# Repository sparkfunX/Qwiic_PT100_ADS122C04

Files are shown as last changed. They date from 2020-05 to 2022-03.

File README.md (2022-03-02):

# Qwiic PT100 ADS122C04

The Qwiic PT100 is based on the TI ADS122C04 and allows you to measure temperature accurately from
100 Ohm Platinum Resistance Thermometers using 2, 3 or 4-wire connections



[Qwiic PT100 - ADS122C04 (SPX-16770)](https://www.sparkfun.com/products/16770)

The ADS122C04 is a precision 24-bit delta-sigma analog to digital converter. It can measure voltage very
accurately through two differential or four single-ended inputs. It has a flexible input multiplexer,
a low-noise programmable gain amplifier, two programmable current sources, a voltage reference
and an in-built precision temperature sensor. In summary, it contains everything you need to measure
temperature accurately from remote sensors.

The Qwiic PT100 is dedicated to reading the temperature of 100 Ohm Platinum Resistance Thermometers
using 2, 3 or 4-wire connections. Using a 3 or 4-wire connection allows the ADS122C04 to automatically
compensate for the cable resistance. The differential input provides noise rejection for industrial
applications.

The ADS122C04 features a 2-wire I2C-compatible interface. The chip address can be changed by
reconfiguring the two jumpers A0 and A1. Please see the schematic for further details.

## Repository Contents
- **/Hardware** - Eagle schematic and PCB design files
- **/Documents** - contains the TI datasheet and application reports
- **LICENSE.md** contains the licence information

## Library

- **[Arduino Library](https://github.com/sparkfun/SparkFun_ADS122C04_ADC_Arduino_Library)** - Library to support the ADS122C04

## Probe Disconnection

If you need to test if the PT100 probe has been connected correctly to the ADS122C04, you may find [this discussion](https://forum.sparkfun.com/viewtopic.php?p=231735#p231735) useful.

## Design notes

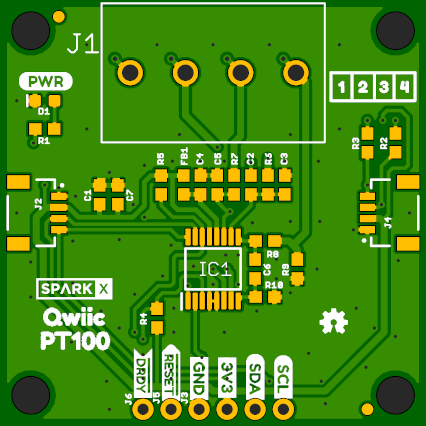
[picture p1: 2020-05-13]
img/Top.png

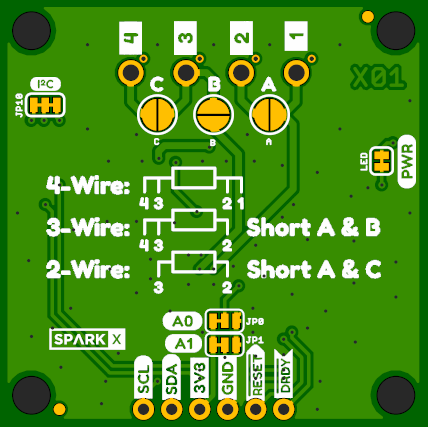
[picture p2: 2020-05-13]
img/Bottom.png

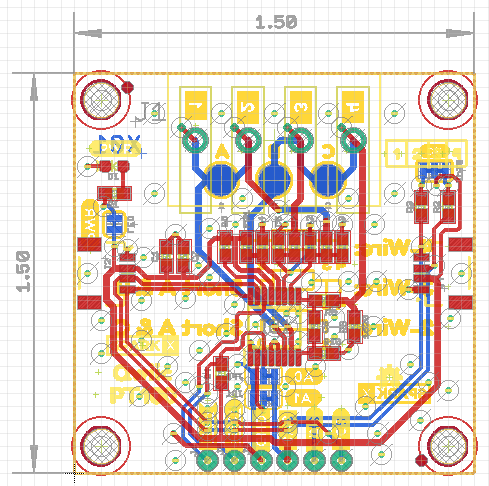
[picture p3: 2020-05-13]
img/Dimension.png

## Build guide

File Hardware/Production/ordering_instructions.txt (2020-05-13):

panel size, 168x161mm
PCB thickness, 1.6mm
number of layers, 2
soldermask color, Black
silkscreen color, White
oz copper, 1oz
finish, HASL lead free
stencils, top+bottom
pcs per panel, 16
min trace width, 0.3048mm / 0.0120in
min drill size, 0.3048mm / 0.0120in

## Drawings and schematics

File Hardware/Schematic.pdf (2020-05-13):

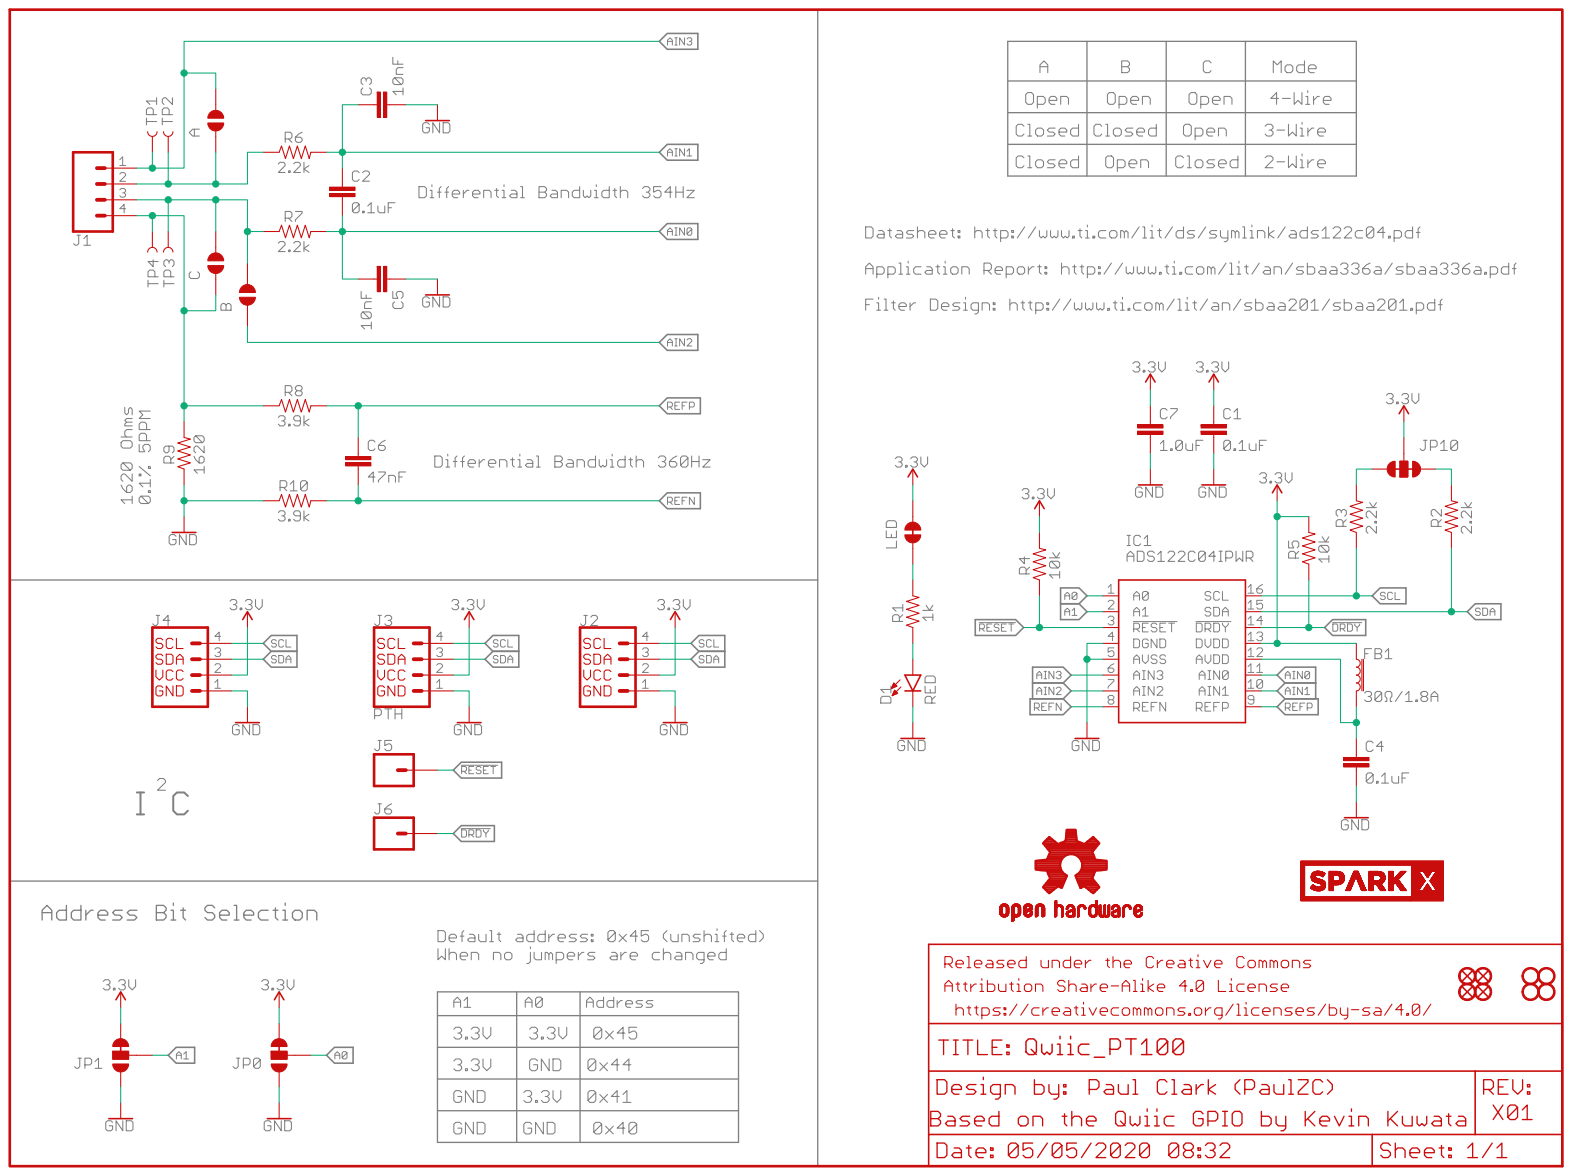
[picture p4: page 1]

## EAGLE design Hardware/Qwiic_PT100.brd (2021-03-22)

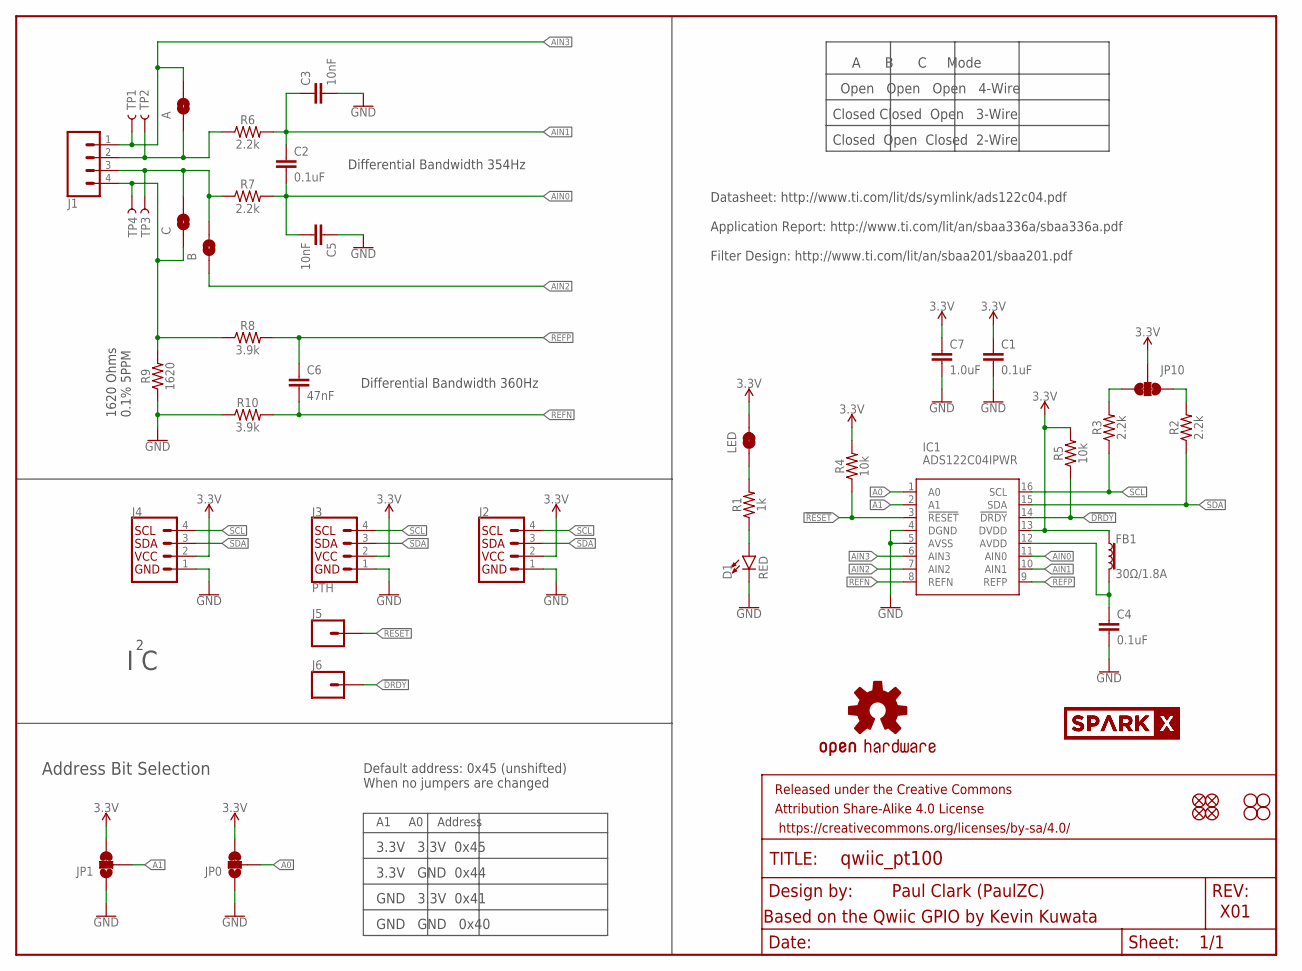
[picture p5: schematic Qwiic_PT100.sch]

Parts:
A: JUMPER-SMT_2_NO_SILK_ROUND; SMT-JUMPER_2_NO_SILK_ROUND
B: JUMPER-SMT_2_NO_SILK_ROUND; SMT-JUMPER_2_NO_SILK_ROUND
C: JUMPER-SMT_2_NO_SILK_ROUND; SMT-JUMPER_2_NO_SILK_ROUND
C1, C2, C4: 0.1uF; 0603
C3, C5: 10nF; 0603
C6: 47nF; 0603
C7: 1.0uF; 0603
D1: RED; LED-0603
FB1: 30Ω/1.8A; 0603
FD1, FD2: FIDUCIAL1X2; FIDUCIAL-1X2
FRAME1: FRAME-LETTER; CREATIVE_COMMONS
H1, H2: STAND-OFF
IC1: ADS122C04IPWR; SOP65P640X120-16N
J1: CONN_04LATCH; LATCHTERMINAL-5MM-4
J2, J4: QWIIC_RIGHT_ANGLE; JST04_1MM_RA
J3: PTH; 1X04_NO_SILK
J5, J6: CONN_01PTH_NO_SILK_YES_STOP; 1X01_NO_SILK
JP0, JP1: JUMPER-SMT_3_1-NC_TRACE_SILK; SMT-JUMPER_3_1-NC_TRACE_SILK
JP2, JP6: FIDUCIAL1X2; FIDUCIAL-1X2
JP3, JP4: STAND-OFF
JP10: JUMPER-SMT_3_2-NC_TRACE_SILK; SMT-JUMPER_3_2-NC_TRACE_SILK
LED: JUMPER-SMT_2_NC_TRACE_SILK; SMT-JUMPER_2_NC_TRACE_SILK
LOGO1: OSHW-LOGOMINI; OSHW-LOGO-MINI
R1: 1k; 0603
R2, R3, R6, R7: 2.2k; 0603
R4, R5: 10k; 0603
R8, R10: 3.9k; 0603
R9: 1620; 0603
TP1, TP2, TP3, TP4: TEST-POINTTP_15TH_THRU; TP_15TH
U$1, U$2: SPARKX-LOGO3; SPARKX-SMALL

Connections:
3.3V: C1.1, C7.1, FB1.1, IC1.13 (DVDD), J2.2, J3.2, J4.2, JP0.3, JP1.3, JP10.2, LED.2, R4.2, R5.2
!DRDY: IC1.14 (!DRDY), J6.1, R5.1
!RESET: IC1.3 (!RESET), J5.1, R4.1
A0: IC1.1 (A0), JP0.2
A1: IC1.2 (A1), JP1.2
AIN0: C2.2, C5.2, IC1.11 (AIN0), R7.2
AIN1: C2.1, C3.1, IC1.10 (AIN1), R6.2
AIN2: B.1, IC1.7 (AIN2)
AIN3: A.2, IC1.6 (AIN3), J1.1, TP1.P$1
GND: C1.2, C3.2, C4.2, C5.1, C7.2, D1.C, IC1.4 (DGND), IC1.5 (AVSS), J2.1, J3.1, J4.1, JP0.1, JP1.1, R9.1, R10.1
unnamed: A.1, J1.2, R6.1, TP2.P$1
unnamed: D1.A, R1.1
unnamed: LED.1, R1.2
unnamed: C4.1, FB1.2, IC1.12 (AVDD)
unnamed: B.2, C.2, J1.3, R7.1, TP3.P$1
unnamed: C.1, J1.4, R8.1, R9.2, TP4.P$1
REFN: C6.2, IC1.8 (REFN), R10.2
REFP: C6.1, IC1.9 (REFP), R8.2
SCL: IC1.16 (SCL), J2.4, J3.4, J4.4, R3.1
SCL_PU1: JP10.1, R2.2
SDA: IC1.15 (SDA), J2.3, J3.3, J4.3, R2.1
SDA_PU1: JP10.3, R3.2

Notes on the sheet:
Paul Clark (PaulZC)
X01
I C
Address Bit Selection
A1 A0 Address
3.3V 3.3V 0x45
3.3V GND 0x44
GND 3.3V 0x41
GND GND 0x40
Default address: 0x45 (unshifted) When no jumpers are changed
Based on the Qwiic GPIO by Kevin Kuwata
A B C Mode
Open Open Open 4-Wire
Closed Closed Open 3-Wire
Closed Open Closed 2-Wire
Datasheet: http://www.ti.com/lit/ds/symlink/ads122c04.pdf Application Report: http://www.ti.com/lit/an/sbaa336a/sbaa336a.pdf Filter Design: http://www.ti.com/lit/an/sbaa201/sbaa201.pdf
1620 Ohms 0.1% 5PPM
Differential Bandwidth 354Hz
Differential Bandwidth 360Hz

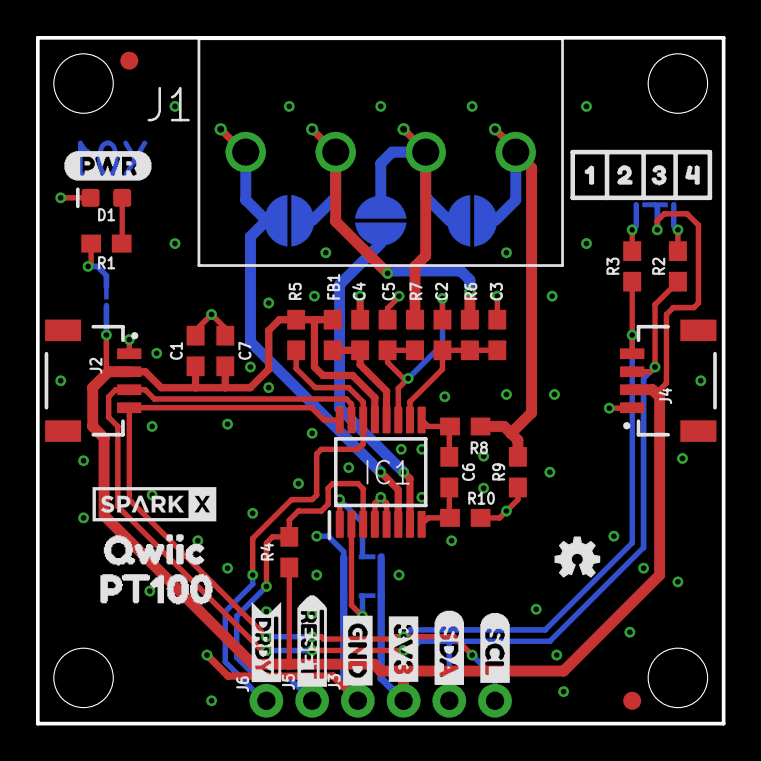
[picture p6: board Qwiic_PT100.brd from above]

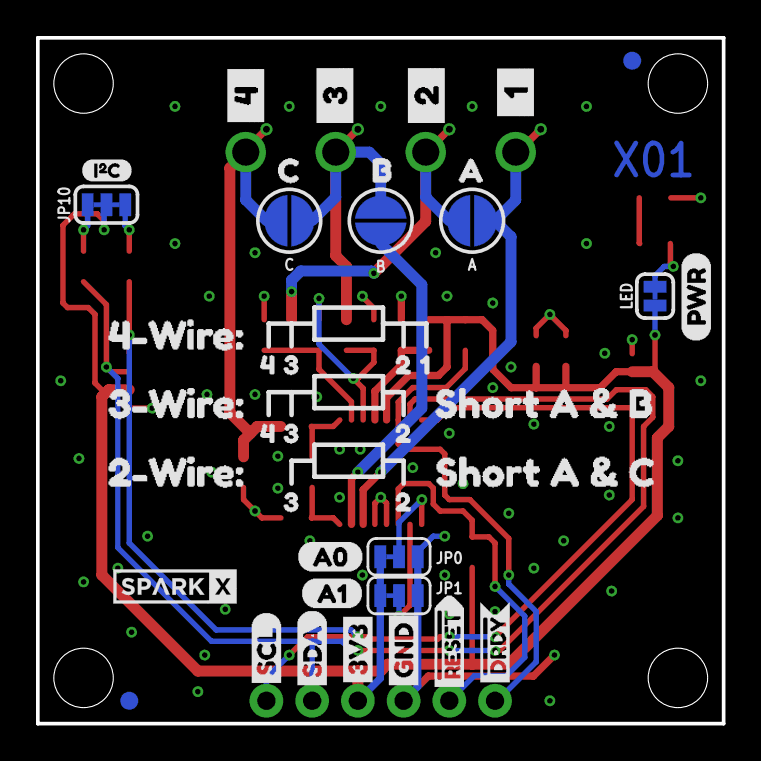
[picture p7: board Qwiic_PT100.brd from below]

Board: 2 copper layers, 38.1 x 38.1 mm, 93 parts (41 on the bottom side), 22 nets.

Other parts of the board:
U$3, U$26: 3V33
U$4: _1_0
U$5: A11
U$6: _2_0
U$7, U$25: GND4
U$8: PT1000
U$9: SCL6
U$10: SDA5
U$11: A00
U$12: _3_0
U$13: _4_0
U$14, U$15: #DRDY0
U$16, U$17: #RESET0
U$18: A0
U$19: B0
U$20: I_SUPER2_C-()-03
U$21, U$30, U$44: 40
U$22: C0
U$23: SCL0
U$24: SDA1
U$27, U$34, U$38, U$47: 31
U$28, U$33, U$37, U$46: 20
U$29, U$35: 15
U$31: 2#WIRE#0
U$32: QWIIC1
U$36: 3#WIRE#0
U$39, U$40: PWR0
U$41: 4#WIRE#0
U$42: SHORT_A_#_B0
U$43: SHORT_A_#_C0

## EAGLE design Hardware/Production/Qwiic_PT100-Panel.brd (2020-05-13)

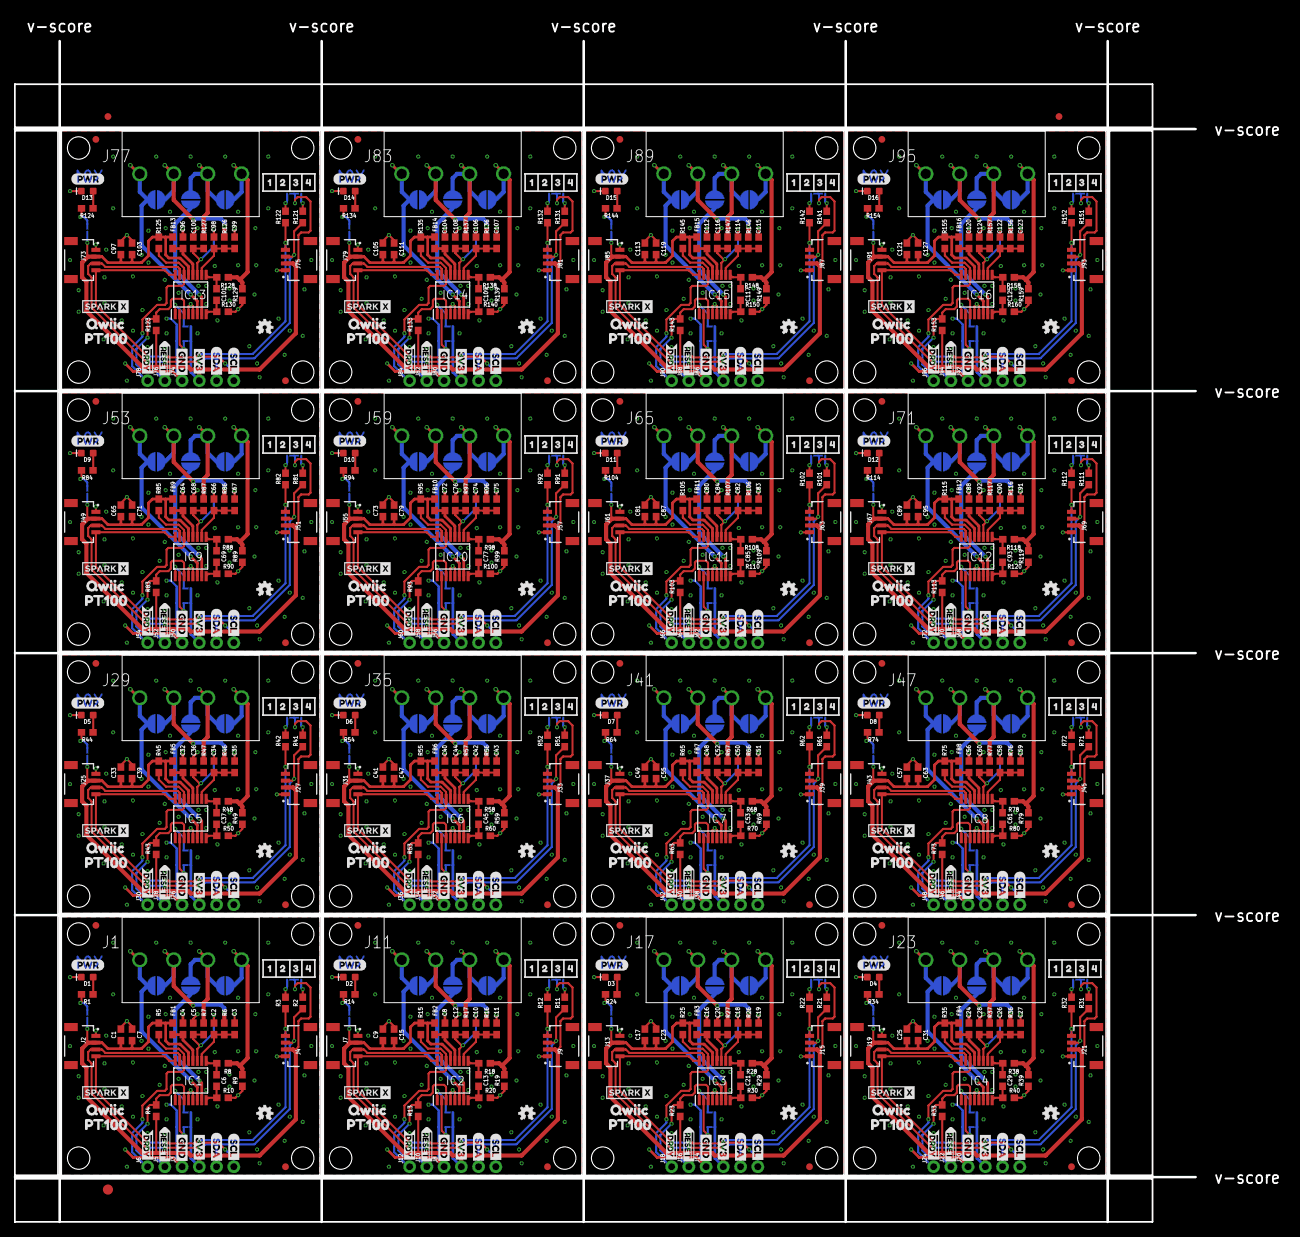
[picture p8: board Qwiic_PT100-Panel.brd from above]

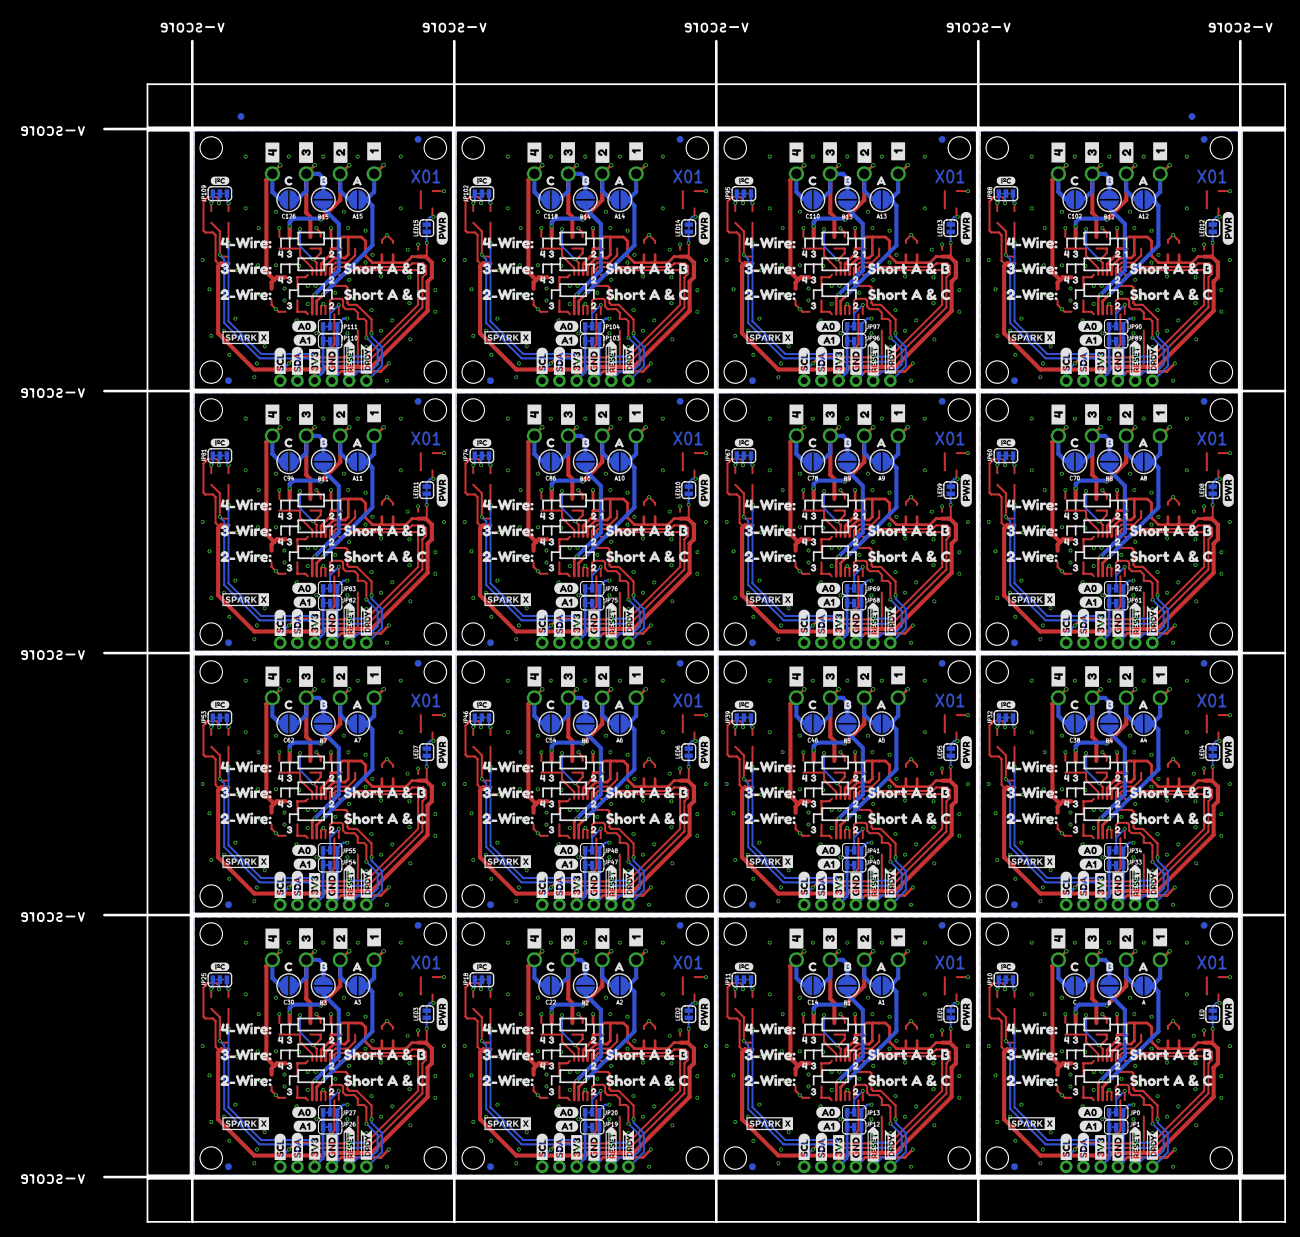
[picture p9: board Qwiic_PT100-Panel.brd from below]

Board: 2 copper layers, 174.0 x 174.0 mm, 1477 parts (658 on the bottom side), 352 nets.

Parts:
A, A1, A2, A3, A4, A5, A6, A7, A8, A9, A10, A11, A12, A13, A14, A15: JUMPER-SMT_2_NO_SILK_ROUND; SMT-JUMPER_2_NO_SILK_ROUND
B, B1, B2, B3, B4, B5, B6, B7, B8, B9, B10, B11, B12, B13, B14, B15: JUMPER-SMT_2_NO_SILK_ROUND; SMT-JUMPER_2_NO_SILK_ROUND
C, C14, C22, C30, C38, C46, C54, C62, C70, C78, C86, C94, C102, C110, C118, C126: JUMPER-SMT_2_NO_SILK_ROUND; SMT-JUMPER_2_NO_SILK_ROUND
C1, C2, C4, C8, C9, C10, C16, C17, C18, C24, C25, C26, C32, C33, C34, C40, C41, C42, C48, C49, C50, C56, C57, C58, C64, C65, C66, C72, C73, C74, C80, C81, C82, C88, C89, C90, C96, C97, C98, C104, C105, C106, C112, C113, C114, C120, C121, C122: 0.1uF; 0603
C3, C5, C11, C12, C19, C20, C27, C28, C35, C36, C43, C44, C51, C52, C59, C60, C67, C68, C75, C76, C83, C84, C91, C92, C99, C100, C107, C108, C115, C116, C123, C124: 10nF; 0603
C6, C13, C21, C29, C37, C45, C53, C61, C69, C77, C85, C93, C101, C109, C117, C125: 47nF; 0603
C7, C15, C23, C31, C39, C47, C55, C63, C71, C79, C87, C95, C103, C111, C119, C127: 1.0uF; 0603
D1, D2, D3, D4, D5, D6, D7, D8, D9, D10, D11, D12, D13, D14, D15, D16: RED; LED-0603
E$1, E$2, E$3, E$4: FIDUCIAL-1X2
E$5: FIDUCIAL-1.5X3
FB1, FB2, FB3, FB4, FB5, FB6, FB7, FB8, FB9, FB10, FB11, FB12, FB13, FB14, FB15, FB16: 30Ω/1.8A; 0603
FD1, FD2, FD3, FD4, FD5, FD6, FD7, FD8, FD9, FD10, FD11, FD12, FD13, FD14, FD15, FD16, FD17, FD18, FD19, FD20, FD21, FD22, FD23, FD24, FD25, FD26, FD27, FD28, FD29, FD30, FD31, FD32: FIDUCIAL1X2; FIDUCIAL-1X2
H1, H2, H3, H4, H5, H6, H7, H8, H9, H10, H11, H12, H13, H14, H15, H16, H17, H18, H19, H20, H21, H22, H23, H24, H25, H26, H27, H28, H29, H30, H31, H32: STAND-OFF
IC1, IC2, IC3, IC4, IC5, IC6, IC7, IC8, IC9, IC10, IC11, IC12, IC13, IC14, IC15, IC16: ADS122C04IPWR; SOP65P640X120-16N
J1, J11, J17, J23, J29, J35, J41, J47, J53, J59, J65, J71, J77, J83, J89, J95: LATCHTERMINAL-5MM-4
J2, J4, J7, J9, J13, J15, J19, J21, J25, J27, J31, J33, J37, J39, J43, J45, J49, J51, J55, J57, J61, J63, J67, J69, J73, J75, J79, J81, J85, J87, J91, J93: QWIIC_RIGHT_ANGLE; JST04_1MM_RA
J3, J8, J14, J20, J26, J32, J38, J44, J50, J56, J62, J68, J74, J80, J86, J92: PTH; 1X04_NO_SILK
J5, J6, J10, J12, J16, J18, J22, J24, J28, J30, J34, J36, J40, J42, J46, J48, J52, J54, J58, J60, J64, J66, J70, J72, J76, J78, J82, J84, J88, J90, J94, J96: 1X01_NO_SILK
JP0, JP1, JP12, JP13, JP19, JP20, JP26, JP27, JP33, JP34, JP40, JP41, JP47, JP48, JP54, JP55, JP61, JP62, JP68, JP69, JP75, JP76, JP82, JP83, JP89, JP90, JP96, JP97, JP103, JP104, JP110, JP111: JUMPER-SMT_3_1-NC_TRACE_SILK; SMT-JUMPER_3_1-NC_TRACE_SILK
JP2, JP6, JP8, JP9, JP16, JP17, JP23, JP24, JP30, JP31, JP37, JP38, JP44, JP45, JP51, JP52, JP58, JP59, JP65, JP66, JP72, JP73, JP79, JP80, JP86, JP87, JP93, JP94, JP100, JP101, JP107, JP108: FIDUCIAL1X2; FIDUCIAL-1X2
JP3, JP4, JP5, JP7, JP14, JP15, JP21, JP22, JP28, JP29, JP35, JP36, JP42, JP43, JP49, JP50, JP56, JP57, JP63, JP64, JP70, JP71, JP77, JP78, JP84, JP85, JP91, JP92, JP98, JP99, JP105, JP106: STAND-OFF
JP10, JP11, JP18, JP25, JP32, JP39, JP46, JP53, JP60, JP67, JP74, JP81, JP88, JP95, JP102, JP109: JUMPER-SMT_3_2-NC_TRACE_SILK; SMT-JUMPER_3_2-NC_TRACE_SILK
LED, LED1, LED2, LED3, LED4, LED5, LED6, LED7, LED8, LED9, LED10, LED11, LED12, LED13, LED14, LED15: JUMPER-SMT_2_NC_TRACE_SILK; SMT-JUMPER_2_NC_TRACE_SILK
LOGO1, LOGO2, LOGO3, LOGO4, LOGO5, LOGO6, LOGO7, LOGO8, LOGO9, LOGO10, LOGO11, LOGO12, LOGO13, LOGO14, LOGO15, LOGO16: OSHW-LOGOMINI; OSHW-LOGO-MINI
R1, R14, R24, R34, R44, R54, R64, R74, R84, R94, R104, R114, R124, R134, R144, R154: 1k; 0603
R2, R3, R6, R7, R11, R12, R16, R17, R21, R22, R26, R27, R31, R32, R36, R37, R41, R42, R46, R47, R51, R52, R56, R57, R61, R62, R66, R67, R71, R72, R76, R77, R81, R82, R86, R87, R91, R92, R96, R97, R101, R102, R106, R107, R111, R112, R116, R117, R121, R122, R126, R127, R131, R132, R136, R137, R141, R142, R146, R147, R151, R152, R156, R157: 2.2k; 0603
R4, R5, R13, R15, R23, R25, R33, R35, R43, R45, R53, R55, R63, R65, R73, R75, R83, R85, R93, R95, R103, R105, R113, R115, R123, R125, R133, R135, R143, R145, R153, R155: 10k; 0603
R8, R10, R18, R20, R28, R30, R38, R40, R48, R50, R58, R60, R68, R70, R78, R80, R88, R90, R98, R100, R108, R110, R118, R120, R128, R130, R138, R140, R148, R150, R158, R160: 3.9k; 0603
R9, R19, R29, R39, R49, R59, R69, R79, R89, R99, R109, R119, R129, R139, R149, R159: 1620; 0603
TP1, TP2, TP3, TP4, TP5, TP6, TP7, TP8, TP9, TP10, TP11, TP12, TP13, TP14, TP15, TP16, TP17, TP18, TP19, TP20, TP21, TP22, TP23, TP24, TP25, TP26, TP27, TP28, TP29, TP30, TP31, TP32, TP33, TP34, TP35, TP36, TP37, TP38, TP39, TP40, TP41, TP42, TP43, TP44, TP45, TP46, TP47, TP48, TP49, TP50, TP51, TP52, TP53, TP54, TP55, TP56, TP57, TP58, TP59, TP60, TP61, TP62, TP63, TP64: TEST-POINTTP_15TH_THRU; TP_15TH
U$1, U$2, U$45, U$48, U$93, U$94, U$139, U$140, U$185, U$186, U$231, U$232, U$277, U$278, U$323, U$324, U$369, U$370, U$415, U$416, U$461, U$462, U$507, U$508, U$553, U$554, U$599, U$600, U$645, U$646, U$691, U$692: SPARKX-LOGO3; SPARKX-SMALL
U$3, U$26, U$49, U$59, U$95, U$105, U$141, U$151, U$187, U$197, U$233, U$243, U$279, U$289, U$325, U$335, U$371, U$381, U$417, U$427, U$463, U$473, U$509, U$519, U$555, U$565, U$601, U$611, U$647, U$657, U$693, U$703: 3V33
U$4, U$66, U$112, U$158, U$204, U$250, U$296, U$342, U$388, U$434, U$480, U$526, U$572, U$618, U$664, U$710: _1_0
U$5, U$50, U$96, U$142, U$188, U$234, U$280, U$326, U$372, U$418, U$464, U$510, U$556, U$602, U$648, U$694: A11
U$6, U$67, U$113, U$159, U$205, U$251, U$297, U$343, U$389, U$435, U$481, U$527, U$573, U$619, U$665, U$711: _2_0
U$7, U$25, U$51, U$58, U$97, U$104, U$143, U$150, U$189, U$196, U$235, U$242, U$281, U$288, U$327, U$334, U$373, U$380, U$419, U$426, U$465, U$472, U$511, U$518, U$557, U$564, U$603, U$610, U$649, U$656, U$695, U$702: GND4
U$8, U$78, U$124, U$170, U$216, U$262, U$308, U$354, U$400, U$446, U$492, U$538, U$584, U$630, U$676, U$722: PT1000
U$9, U$52, U$98, U$144, U$190, U$236, U$282, U$328, U$374, U$420, U$466, U$512, U$558, U$604, U$650, U$696: SCL6
U$10, U$53, U$99, U$145, U$191, U$237, U$283, U$329, U$375, U$421, U$467, U$513, U$559, U$605, U$651, U$697: SDA5
U$11, U$54, U$100, U$146, U$192, U$238, U$284, U$330, U$376, U$422, U$468, U$514, U$560, U$606, U$652, U$698: A00
U$12, U$68, U$114, U$160, U$206, U$252, U$298, U$344, U$390, U$436, U$482, U$528, U$574, U$620, U$666, U$712: _3_0
U$13, U$69, U$115, U$161, U$207, U$253, U$299, U$345, U$391, U$437, U$483, U$529, U$575, U$621, U$667, U$713: _4_0
U$14, U$15, U$70, U$71, U$116, U$117, U$162, U$163, U$208, U$209, U$254, U$255, U$300, U$301, U$346, U$347, U$392, U$393, U$438, U$439, U$484, U$485, U$530, U$531, U$576, U$577, U$622, U$623, U$668, U$669, U$714, U$715: #DRDY0
U$16, U$17, U$72, U$73, U$118, U$119, U$164, U$165, U$210, U$211, U$256, U$257, U$302, U$303, U$348, U$349, U$394, U$395, U$440, U$441, U$486, U$487, U$532, U$533, U$578, U$579, U$624, U$625, U$670, U$671, U$716, U$717: #RESET0
U$18, U$74, U$120, U$166, U$212, U$258, U$304, U$350, U$396, U$442, U$488, U$534, U$580, U$626, U$672, U$718: A0
U$19, U$75, U$121, U$167, U$213, U$259, U$305, U$351, U$397, U$443, U$489, U$535, U$581, U$627, U$673, U$719: B0
U$20, U$55, U$101, U$147, U$193, U$239, U$285, U$331, U$377, U$423, U$469, U$515, U$561, U$607, U$653, U$699: I_SUPER2_C-()-03
U$21, U$30, U$44, U$77, U$86, U$89, U$123, U$132, U$135, U$169, U$178, U$181, U$215, U$224, U$227, U$261, U$270, U$273, U$307, U$316, U$319, U$353, U$362, U$365, U$399, U$408, U$411, U$445, U$454, U$457, U$491, U$500, U$503, U$537, U$546, U$549, U$583, U$592, U$595, U$629, U$638, U$641, U$675, U$684, U$687, U$721, U$730, U$733: 40
U$22, U$76, U$122, U$168, U$214, U$260, U$306, U$352, U$398, U$444, U$490, U$536, U$582, U$628, U$674, U$720: C0
U$23, U$56, U$102, U$148, U$194, U$240, U$286, U$332, U$378, U$424, U$470, U$516, U$562, U$608, U$654, U$700: SCL0
U$24, U$57, U$103, U$149, U$195, U$241, U$287, U$333, U$379, U$425, U$471, U$517, U$563, U$609, U$655, U$701: SDA1
U$27, U$34, U$38, U$47, U$63, U$85, U$88, U$90, U$109, U$131, U$134, U$136, U$155, U$177, U$180, U$182, U$201, U$223, U$226, U$228, U$247, U$269, U$272, U$274, U$293, U$315, U$318, U$320, U$339, U$361, U$364, U$366, U$385, U$407, U$410, U$412, U$431, U$453, U$456, U$458, U$477, U$499, U$502, U$504, U$523, U$545, U$548, U$550, U$569, U$591, U$594, U$596, U$615, U$637, U$640, U$642, U$661, U$683, U$686, U$688, U$707, U$729, U$732, U$734: 31
U$28, U$33, U$37, U$46, U$62, U$84, U$87, U$91, U$108, U$130, U$133, U$137, U$154, U$176, U$179, U$183, U$200, U$222, U$225, U$229, U$246, U$268, U$271, U$275, U$292, U$314, U$317, U$321, U$338, U$360, U$363, U$367, U$384, U$406, U$409, U$413, U$430, U$452, U$455, U$459, U$476, U$498, U$501, U$505, U$522, U$544, U$547, U$551, U$568, U$590, U$593, U$597, U$614, U$636, U$639, U$643, U$660, U$682, U$685, U$689, U$706, U$728, U$731, U$735: 20
U$29, U$35, U$61, U$92, U$107, U$138, U$153, U$184, U$199, U$230, U$245, U$276, U$291, U$322, U$337, U$368, U$383, U$414, U$429, U$460, U$475, U$506, U$521, U$552, U$567, U$598, U$613, U$644, U$659, U$690, U$705, U$736: 15
U$31, U$79, U$125, U$171, U$217, U$263, U$309, U$355, U$401, U$447, U$493, U$539, U$585, U$631, U$677, U$723: 2#WIRE#0
U$32, U$60, U$106, U$152, U$198, U$244, U$290, U$336, U$382, U$428, U$474, U$520, U$566, U$612, U$658, U$704: QWIIC1
U$36, U$80, U$126, U$172, U$218, U$264, U$310, U$356, U$402, U$448, U$494, U$540, U$586, U$632, U$678, U$724: 3#WIRE#0
U$39, U$40, U$64, U$65, U$110, U$111, U$156, U$157, U$202, U$203, U$248, U$249, U$294, U$295, U$340, U$341, U$386, U$387, U$432, U$433, U$478, U$479, U$524, U$525, U$570, U$571, U$616, U$617, U$662, U$663, U$708, U$709: PWR0
U$41, U$81, U$127, U$173, U$219, U$265, U$311, U$357, U$403, U$449, U$495, U$541, U$587, U$633, U$679, U$725: 4#WIRE#0
U$42, U$82, U$128, U$174, U$220, U$266, U$312, U$358, U$404, U$450, U$496, U$542, U$588, U$634, U$680, U$726: SHORT_A_#_B0
U$43, U$83, U$129, U$175, U$221, U$267, U$313, U$359, U$405, U$451, U$497, U$543, U$589, U$635, U$681, U$727: SHORT_A_#_C0

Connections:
3.3V: C1.1, C7.1, FB1.1, IC1.13, J2.2, J3.2, J4.2, JP0.3, JP1.3, JP10.2, LED.2, R4.2, R5.2
3.3V1: C9.1, C15.1, FB2.1, IC2.13, J7.2, J8.2, J9.2, JP11.2, JP12.3, JP13.3, LED1.2, R13.2, R15.2
3.3V2: C17.1, C23.1, FB3.1, IC3.13, J13.2, J14.2, J15.2, JP18.2, JP19.3, JP20.3, LED2.2, R23.2, R25.2
3.3V3: C25.1, C31.1, FB4.1, IC4.13, J19.2, J20.2, J21.2, JP25.2, JP26.3, JP27.3, LED3.2, R33.2, R35.2
3.3V4: C33.1, C39.1, FB5.1, IC5.13, J25.2, J26.2, J27.2, JP32.2, JP33.3, JP34.3, LED4.2, R43.2, R45.2
3.3V5: C41.1, C47.1, FB6.1, IC6.13, J31.2, J32.2, J33.2, JP39.2, JP40.3, JP41.3, LED5.2, R53.2, R55.2
3.3V6: C49.1, C55.1, FB7.1, IC7.13, J37.2, J38.2, J39.2, JP46.2, JP47.3, JP48.3, LED6.2, R63.2, R65.2
3.3V7: C57.1, C63.1, FB8.1, IC8.13, J43.2, J44.2, J45.2, JP53.2, JP54.3, JP55.3, LED7.2, R73.2, R75.2
3.3V8: C65.1, C71.1, FB9.1, IC9.13, J49.2, J50.2, J51.2, JP60.2, JP61.3, JP62.3, LED8.2, R83.2, R85.2
3.3V9: C73.1, C79.1, FB10.1, IC10.13, J55.2, J56.2, J57.2, JP67.2, JP68.3, JP69.3, LED9.2, R93.2, R95.2
3.3V10: C81.1, C87.1, FB11.1, IC11.13, J61.2, J62.2, J63.2, JP74.2, JP75.3, JP76.3, LED10.2, R103.2, R105.2
3.3V11: C89.1, C95.1, FB12.1, IC12.13, J67.2, J68.2, J69.2, JP81.2, JP82.3, JP83.3, LED11.2, R113.2, R115.2
3.3V12: C97.1, C103.1, FB13.1, IC13.13, J73.2, J74.2, J75.2, JP88.2, JP89.3, JP90.3, LED12.2, R123.2, R125.2
3.3V13: C105.1, C111.1, FB14.1, IC14.13, J79.2, J80.2, J81.2, JP95.2, JP96.3, JP97.3, LED13.2, R133.2, R135.2
3.3V14: C113.1, C119.1, FB15.1, IC15.13, J85.2, J86.2, J87.2, JP102.2, JP103.3, JP104.3, LED14.2, R143.2, R145.2
3.3V15: C121.1, C127.1, FB16.1, IC16.13, J91.2, J92.2, J93.2, JP109.2, JP110.3, JP111.3, LED15.2, R153.2, R155.2
!DRDY: IC1.14, J6.1, R5.1
!DRDY1: IC2.14, J12.1, R15.1
!DRDY2: IC3.14, J18.1, R25.1
!DRDY3: IC4.14, J24.1, R35.1
!DRDY4: IC5.14, J30.1, R45.1
!DRDY5: IC6.14, J36.1, R55.1
!DRDY6: IC7.14, J42.1, R65.1
!DRDY7: IC8.14, J48.1, R75.1
!DRDY8: IC9.14, J54.1, R85.1
!DRDY9: IC10.14, J60.1, R95.1
!DRDY10: IC11.14, J66.1, R105.1
!DRDY11: IC12.14, J72.1, R115.1
!DRDY12: IC13.14, J78.1, R125.1
!DRDY13: IC14.14, J84.1, R135.1
!DRDY14: IC15.14, J90.1, R145.1
!DRDY15: IC16.14, J96.1, R155.1
!RESET: IC1.3, J5.1, R4.1
!RESET1: IC2.3, J10.1, R13.1
!RESET2: IC3.3, J16.1, R23.1
!RESET3: IC4.3, J22.1, R33.1
!RESET4: IC5.3, J28.1, R43.1
!RESET5: IC6.3, J34.1, R53.1
!RESET6: IC7.3, J40.1, R63.1
!RESET7: IC8.3, J46.1, R73.1
!RESET8: IC9.3, J52.1, R83.1
!RESET9: IC10.3, J58.1, R93.1
!RESET10: IC11.3, J64.1, R103.1
!RESET11: IC12.3, J70.1, R113.1
!RESET12: IC13.3, J76.1, R123.1
!RESET13: IC14.3, J82.1, R133.1
!RESET14: IC15.3, J88.1, R143.1
!RESET15: IC16.3, J94.1, R153.1
A0: IC1.1, JP0.2
A1: IC1.2, JP1.2
A2: IC2.1, JP13.2
A3: IC2.2, JP12.2
A4: IC3.1, JP20.2
A5: IC3.2, JP19.2
A6: IC4.1, JP27.2
A7: IC4.2, JP26.2
A8: IC5.1, JP34.2
A9: IC5.2, JP33.2
A10: IC6.1, JP41.2
A11: IC6.2, JP40.2
A12: IC7.1, JP48.2
A13: IC7.2, JP47.2
A14: IC8.1, JP55.2
A15: IC8.2, JP54.2
A16: IC9.1, JP62.2
A17: IC9.2, JP61.2
A18: IC10.1, JP69.2
A19: IC10.2, JP68.2
A20: IC11.1, JP76.2
A21: IC11.2, JP75.2
A22: IC12.1, JP83.2
A23: IC12.2, JP82.2
A24: IC13.1, JP90.2
A25: IC13.2, JP89.2
A26: IC14.1, JP97.2
A27: IC14.2, JP96.2
A28: IC15.1, JP104.2
A29: IC15.2, JP103.2
A30: IC16.1, JP111.2
A31: IC16.2, JP110.2
AIN0: C2.2, C5.2, IC1.11, R7.2
AIN1: C2.1, C3.1, IC1.10, R6.2
AIN2: B.1, IC1.7
AIN3: A.2, IC1.6, J1.1, TP1.P$1
AIN4: C10.1, C11.1, IC2.10, R16.2
AIN5: A1.2, IC2.6, J11.1, TP5.P$1
AIN6: B1.1, IC2.7
AIN7: C10.2, C12.2, IC2.11, R17.2
AIN8: C18.1, C19.1, IC3.10, R26.2
AIN9: A2.2, IC3.6, J17.1, TP9.P$1
AIN10: B2.1, IC3.7
AIN11: C18.2, C20.2, IC3.11, R27.2
AIN12: C26.1, C27.1, IC4.10, R36.2
AIN13: A3.2, IC4.6, J23.1, TP13.P$1
AIN14: B3.1, IC4.7
AIN15: C26.2, C28.2, IC4.11, R37.2
AIN16: C34.1, C35.1, IC5.10, R46.2
AIN17: A4.2, IC5.6, J29.1, TP17.P$1
AIN18: B4.1, IC5.7
AIN19: C34.2, C36.2, IC5.11, R47.2
AIN20: C42.1, C43.1, IC6.10, R56.2
AIN21: A5.2, IC6.6, J35.1, TP21.P$1
AIN22: B5.1, IC6.7
AIN23: C42.2, C44.2, IC6.11, R57.2
AIN24: C50.1, C51.1, IC7.10, R66.2
AIN25: A6.2, IC7.6, J41.1, TP25.P$1
AIN26: B6.1, IC7.7
AIN27: C50.2, C52.2, IC7.11, R67.2
AIN28: C58.1, C59.1, IC8.10, R76.2
AIN29: A7.2, IC8.6, J47.1, TP29.P$1
AIN30: B7.1, IC8.7
AIN31: C58.2, C60.2, IC8.11, R77.2
AIN32: C66.1, C67.1, IC9.10, R86.2
AIN33: A8.2, IC9.6, J53.1, TP33.P$1
AIN34: B8.1, IC9.7
AIN35: C66.2, C68.2, IC9.11, R87.2
AIN36: C74.1, C75.1, IC10.10, R96.2
AIN37: A9.2, IC10.6, J59.1, TP37.P$1
AIN38: B9.1, IC10.7
AIN39: C74.2, C76.2, IC10.11, R97.2
AIN40: C82.1, C83.1, IC11.10, R106.2
AIN41: A10.2, IC11.6, J65.1, TP41.P$1
AIN42: B10.1, IC11.7
AIN43: C82.2, C84.2, IC11.11, R107.2
AIN44: C90.1, C91.1, IC12.10, R116.2
AIN45: A11.2, IC12.6, J71.1, TP45.P$1
AIN46: B11.1, IC12.7
AIN47: C90.2, C92.2, IC12.11, R117.2
AIN48: C98.1, C99.1, IC13.10, R126.2
AIN49: A12.2, IC13.6, J77.1, TP49.P$1
AIN50: B12.1, IC13.7
AIN51: C98.2, C100.2, IC13.11, R127.2
AIN52: C106.1, C107.1, IC14.10, R136.2
AIN53: A13.2, IC14.6, J83.1, TP53.P$1
AIN54: B13.1, IC14.7
AIN55: C106.2, C108.2, IC14.11, R137.2
AIN56: C114.1, C115.1, IC15.10, R146.2
AIN57: A14.2, IC15.6, J89.1, TP57.P$1
AIN58: B14.1, IC15.7
AIN59: C114.2, C116.2, IC15.11, R147.2
AIN60: C122.1, C123.1, IC16.10, R156.2
AIN61: A15.2, IC16.6, J95.1, TP61.P$1
AIN62: B15.1, IC16.7
AIN63: C122.2, C124.2, IC16.11, R157.2
GND: C1.2, C3.2, C4.2, C5.1, C7.2, D1.C, IC1.4, IC1.5, J2.1, J3.1, J4.1, JP0.1, JP1.1, R9.1, R10.1
GND1: C8.2, C9.2, C11.2, C12.1, C15.2, D2.C, IC2.4, IC2.5, J7.1, J8.1, J9.1, JP12.1, JP13.1, R19.1, R20.1
GND2: C16.2, C17.2, C19.2, C20.1, C23.2, D3.C, IC3.4, IC3.5, J13.1, J14.1, J15.1, JP19.1, JP20.1, R29.1, R30.1
GND3: C24.2, C25.2, C27.2, C28.1, C31.2, D4.C, IC4.4, IC4.5, J19.1, J20.1, J21.1, JP26.1, JP27.1, R39.1, R40.1
GND4: C32.2, C33.2, C35.2, C36.1, C39.2, D5.C, IC5.4, IC5.5, J25.1, J26.1, J27.1, JP33.1, JP34.1, R49.1, R50.1
GND5: C40.2, C41.2, C43.2, C44.1, C47.2, D6.C, IC6.4, IC6.5, J31.1, J32.1, J33.1, JP40.1, JP41.1, R59.1, R60.1
GND6: C48.2, C49.2, C51.2, C52.1, C55.2, D7.C, IC7.4, IC7.5, J37.1, J38.1, J39.1, JP47.1, JP48.1, R69.1, R70.1
GND7: C56.2, C57.2, C59.2, C60.1, C63.2, D8.C, IC8.4, IC8.5, J43.1, J44.1, J45.1, JP54.1, JP55.1, R79.1, R80.1
GND8: C64.2, C65.2, C67.2, C68.1, C71.2, D9.C, IC9.4, IC9.5, J49.1, J50.1, J51.1, JP61.1, JP62.1, R89.1, R90.1
GND9: C72.2, C73.2, C75.2, C76.1, C79.2, D10.C, IC10.4, IC10.5, J55.1, J56.1, J57.1, JP68.1, JP69.1, R99.1, R100.1
GND10: C80.2, C81.2, C83.2, C84.1, C87.2, D11.C, IC11.4, IC11.5, J61.1, J62.1, J63.1, JP75.1, JP76.1, R109.1, R110.1
GND11: C88.2, C89.2, C91.2, C92.1, C95.2, D12.C, IC12.4, IC12.5, J67.1, J68.1, J69.1, JP82.1, JP83.1, R119.1, R120.1
GND12: C96.2, C97.2, C99.2, C100.1, C103.2, D13.C, IC13.4, IC13.5, J73.1, J74.1, J75.1, JP89.1, JP90.1, R129.1, R130.1
GND13: C104.2, C105.2, C107.2, C108.1, C111.2, D14.C, IC14.4, IC14.5, J79.1, J80.1, J81.1, JP96.1, JP97.1, R139.1, R140.1
GND14: C112.2, C113.2, C115.2, C116.1, C119.2, D15.C, IC15.4, IC15.5, J85.1, J86.1, J87.1, JP103.1, JP104.1, R149.1, R150.1
GND15: C120.2, C121.2, C123.2, C124.1, C127.2, D16.C, IC16.4, IC16.5, J91.1, J92.1, J93.1, JP110.1, JP111.1, R159.1, R160.1
unnamed: A.1, J1.2, R6.1, TP2.P$1
unnamed: D1.A, R1.1
unnamed: LED.1, R1.2
unnamed: C4.1, FB1.2, IC1.12
unnamed: B.2, C.2, J1.3, R7.1, TP3.P$1
unnamed: C.1, J1.4, R8.1, R9.2, TP4.P$1
unnamed: D2.A, R14.1
unnamed: LED1.1, R14.2
unnamed: C8.1, FB2.2, IC2.12
unnamed: A1.1, J11.2, R16.1, TP6.P$1
unnamed: B1.2, C14.2, J11.3, R17.1, TP7.P$1
unnamed: C14.1, J11.4, R18.1, R19.2, TP8.P$1
unnamed: D3.A, R24.1
unnamed: LED2.1, R24.2
unnamed: C16.1, FB3.2, IC3.12
unnamed: A2.1, J17.2, R26.1, TP10.P$1
unnamed: B2.2, C22.2, J17.3, R27.1, TP11.P$1
unnamed: C22.1, J17.4, R28.1, R29.2, TP12.P$1
unnamed: D4.A, R34.1
unnamed: LED3.1, R34.2
unnamed: C24.1, FB4.2, IC4.12
unnamed: A3.1, J23.2, R36.1, TP14.P$1
unnamed: B3.2, C30.2, J23.3, R37.1, TP15.P$1
unnamed: C30.1, J23.4, R38.1, R39.2, TP16.P$1
unnamed: D5.A, R44.1
unnamed: LED4.1, R44.2
unnamed: C32.1, FB5.2, IC5.12
unnamed: A4.1, J29.2, R46.1, TP18.P$1
unnamed: B4.2, C38.2, J29.3, R47.1, TP19.P$1
unnamed: C38.1, J29.4, R48.1, R49.2, TP20.P$1
unnamed: D6.A, R54.1
unnamed: LED5.1, R54.2
unnamed: C40.1, FB6.2, IC6.12
unnamed: A5.1, J35.2, R56.1, TP22.P$1
unnamed: B5.2, C46.2, J35.3, R57.1, TP23.P$1
unnamed: C46.1, J35.4, R58.1, R59.2, TP24.P$1
unnamed: D7.A, R64.1
unnamed: LED6.1, R64.2
unnamed: C48.1, FB7.2, IC7.12
unnamed: A6.1, J41.2, R66.1, TP26.P$1
unnamed: B6.2, C54.2, J41.3, R67.1, TP27.P$1
unnamed: C54.1, J41.4, R68.1, R69.2, TP28.P$1
unnamed: D8.A, R74.1
unnamed: LED7.1, R74.2
unnamed: C56.1, FB8.2, IC8.12
unnamed: A7.1, J47.2, R76.1, TP30.P$1
unnamed: B7.2, C62.2, J47.3, R77.1, TP31.P$1
unnamed: C62.1, J47.4, R78.1, R79.2, TP32.P$1
unnamed: D9.A, R84.1
unnamed: LED8.1, R84.2
unnamed: C64.1, FB9.2, IC9.12
unnamed: A8.1, J53.2, R86.1, TP34.P$1
unnamed: B8.2, C70.2, J53.3, R87.1, TP35.P$1
unnamed: C70.1, J53.4, R88.1, R89.2, TP36.P$1
unnamed: D10.A, R94.1
unnamed: LED9.1, R94.2
unnamed: C72.1, FB10.2, IC10.12
unnamed: A9.1, J59.2, R96.1, TP38.P$1
unnamed: B9.2, C78.2, J59.3, R97.1, TP39.P$1
unnamed: C78.1, J59.4, R98.1, R99.2, TP40.P$1
unnamed: D11.A, R104.1
unnamed: LED10.1, R104.2
unnamed: C80.1, FB11.2, IC11.12
unnamed: A10.1, J65.2, R106.1, TP42.P$1
unnamed: B10.2, C86.2, J65.3, R107.1, TP43.P$1
unnamed: C86.1, J65.4, R108.1, R109.2, TP44.P$1
unnamed: D12.A, R114.1
unnamed: LED11.1, R114.2
unnamed: C88.1, FB12.2, IC12.12
unnamed: A11.1, J71.2, R116.1, TP46.P$1
unnamed: B11.2, C94.2, J71.3, R117.1, TP47.P$1
unnamed: C94.1, J71.4, R118.1, R119.2, TP48.P$1
unnamed: D13.A, R124.1
unnamed: LED12.1, R124.2
unnamed: C96.1, FB13.2, IC13.12
unnamed: A12.1, J77.2, R126.1, TP50.P$1
unnamed: B12.2, C102.2, J77.3, R127.1, TP51.P$1
unnamed: C102.1, J77.4, R128.1, R129.2, TP52.P$1
unnamed: D14.A, R134.1
unnamed: LED13.1, R134.2
unnamed: C104.1, FB14.2, IC14.12
unnamed: A13.1, J83.2, R136.1, TP54.P$1
unnamed: B13.2, C110.2, J83.3, R137.1, TP55.P$1
unnamed: C110.1, J83.4, R138.1, R139.2, TP56.P$1
unnamed: D15.A, R144.1
unnamed: LED14.1, R144.2
unnamed: C112.1, FB15.2, IC15.12
unnamed: A14.1, J89.2, R146.1, TP58.P$1
unnamed: B14.2, C118.2, J89.3, R147.1, TP59.P$1
unnamed: C118.1, J89.4, R148.1, R149.2, TP60.P$1
unnamed: D16.A, R154.1
unnamed: LED15.1, R154.2
unnamed: C120.1, FB16.2, IC16.12
unnamed: A15.1, J95.2, R156.1, TP62.P$1
unnamed: B15.2, C126.2, J95.3, R157.1, TP63.P$1
unnamed: C126.1, J95.4, R158.1, R159.2, TP64.P$1
REFN: C6.2, IC1.8, R10.2
REFN1: C13.2, IC2.8, R20.2
REFN2: C21.2, IC3.8, R30.2
REFN3: C29.2, IC4.8, R40.2
REFN4: C37.2, IC5.8, R50.2
REFN5: C45.2, IC6.8, R60.2
REFN6: C53.2, IC7.8, R70.2
REFN7: C61.2, IC8.8, R80.2
REFN8: C69.2, IC9.8, R90.2
REFN9: C77.2, IC10.8, R100.2
REFN10: C85.2, IC11.8, R110.2
REFN11: C93.2, IC12.8, R120.2
REFN12: C101.2, IC13.8, R130.2
REFN13: C109.2, IC14.8, R140.2
REFN14: C117.2, IC15.8, R150.2
REFN15: C125.2, IC16.8, R160.2
REFP: C6.1, IC1.9, R8.2
REFP1: C13.1, IC2.9, R18.2
REFP2: C21.1, IC3.9, R28.2
REFP3: C29.1, IC4.9, R38.2
REFP4: C37.1, IC5.9, R48.2
REFP5: C45.1, IC6.9, R58.2
REFP6: C53.1, IC7.9, R68.2
REFP7: C61.1, IC8.9, R78.2
REFP8: C69.1, IC9.9, R88.2
REFP9: C77.1, IC10.9, R98.2
REFP10: C85.1, IC11.9, R108.2
REFP11: C93.1, IC12.9, R118.2
REFP12: C101.1, IC13.9, R128.2
REFP13: C109.1, IC14.9, R138.2
REFP14: C117.1, IC15.9, R148.2
REFP15: C125.1, IC16.9, R158.2
SCL: IC1.16, J2.4, J3.4, J4.4, R3.1
SCL1: IC2.16, J7.4, J8.4, J9.4, R12.1
SCL2: IC3.16, J13.4, J14.4, J15.4, R22.1
SCL3: IC4.16, J19.4, J20.4, J21.4, R32.1
SCL4: IC5.16, J25.4, J26.4, J27.4, R42.1
SCL5: IC6.16, J31.4, J32.4, J33.4, R52.1
SCL6: IC7.16, J37.4, J38.4, J39.4, R62.1
SCL7: IC8.16, J43.4, J44.4, J45.4, R72.1
SCL8: IC9.16, J49.4, J50.4, J51.4, R82.1
SCL9: IC10.16, J55.4, J56.4, J57.4, R92.1
SCL10: IC11.16, J61.4, J62.4, J63.4, R102.1
SCL11: IC12.16, J67.4, J68.4, J69.4, R112.1
SCL12: IC13.16, J73.4, J74.4, J75.4, R122.1
SCL13: IC14.16, J79.4, J80.4, J81.4, R132.1
SCL14: IC15.16, J85.4, J86.4, J87.4, R142.1
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

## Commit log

2020-05-13 Copying across PaulZC/Qwiic_PT100
    [Qwiic_PT100-Panel.GBL, Qwiic_PT100-Panel.GBO, Qwiic_PT100-Panel.GBP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]
2021-03-22 Remove New-Parts
    [Qwiic_PT100.brd, Qwiic_PT100.sch]

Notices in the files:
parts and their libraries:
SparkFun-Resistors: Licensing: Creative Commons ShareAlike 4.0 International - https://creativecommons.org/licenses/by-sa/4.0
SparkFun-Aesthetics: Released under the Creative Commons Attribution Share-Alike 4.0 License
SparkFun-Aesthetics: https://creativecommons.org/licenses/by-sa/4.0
